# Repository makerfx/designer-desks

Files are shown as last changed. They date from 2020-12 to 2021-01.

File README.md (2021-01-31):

# Designer Desks

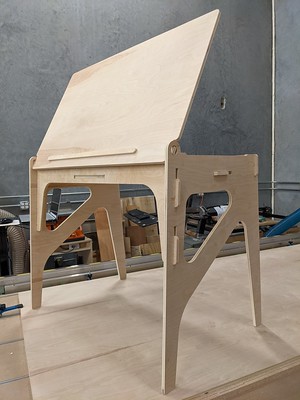
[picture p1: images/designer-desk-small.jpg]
Photo of Designer Desk with top open


The Maker Effect Foundation makes art desks for underprivileged youth in Central Florida. We cut them at MakerFX Makerspace on a Forest CNC MakerFab 5x10 CNC Router with a 5hp spindle, then volunteers sand and prep them for delivery. Each desk is stocked with art supplies. In addition, we have local artists who decorate some of the desks before delivery. 

We hope you will take these designs and make art desks for kids in your area! If you'd like to contact us to learn more, please email us at [info@makerfx.org](mailto:info@makerfx.org)

Design files are stored on GitHub by version. Make sure to use the download button to get the binary version of the file you need.
We have an illustrator outline of the desk top for those creating desk art. [(Download link)](https://github.com/makerfx/designer-desks/raw/main/Art-Desktop-outline.ai)

[Project Photos on Flickr](https://flic.kr/s/aHsmSCwJ4k)

Thanks to [HuntonBrady Architects](http://huntonbrady.com) for the desk design

Thanks to Adam Temple for making awesome assembly instructions!

Thanks to [Forest CNC](http://forestscientific.com/) for helping us obtain an amazing CNC router to make the desks for the initial run in Dec 2020

Thanks to Home Depot for discounting the [1/2 birch plywood](https://www.homedepot.com/p/Columbia-Forest-Products-1-2-in-x-4-ft-x-8-ft-PureBond-Birch-Plywood-833185/100020218) used for the project

Thanks to Boys & Girls Clubs of Central Florida for acting as a distribution partner for the desks

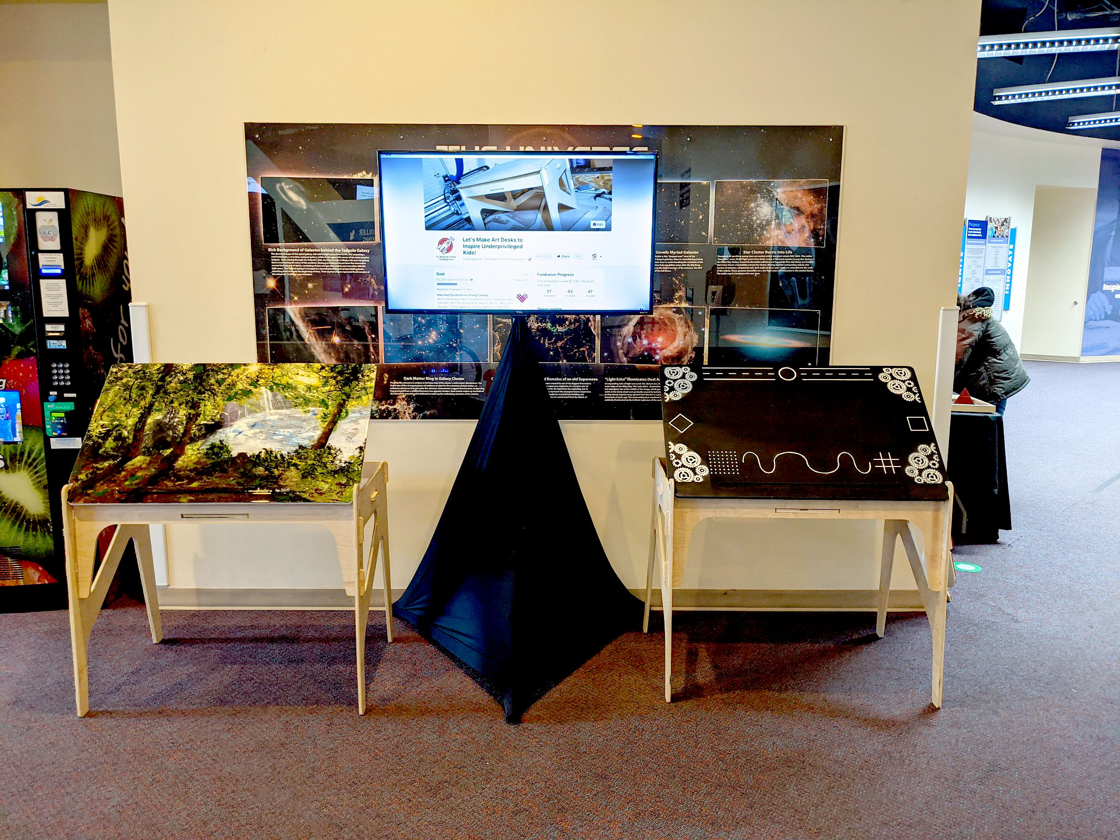
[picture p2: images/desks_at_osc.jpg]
Desks at OSC


This project is funded in part by Orange County Government through the Arts & Cultural Affairs Program.

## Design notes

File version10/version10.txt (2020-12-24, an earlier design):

Merged Layers
Reduced size of tab on lower desk section by 1/32 to help attachment.

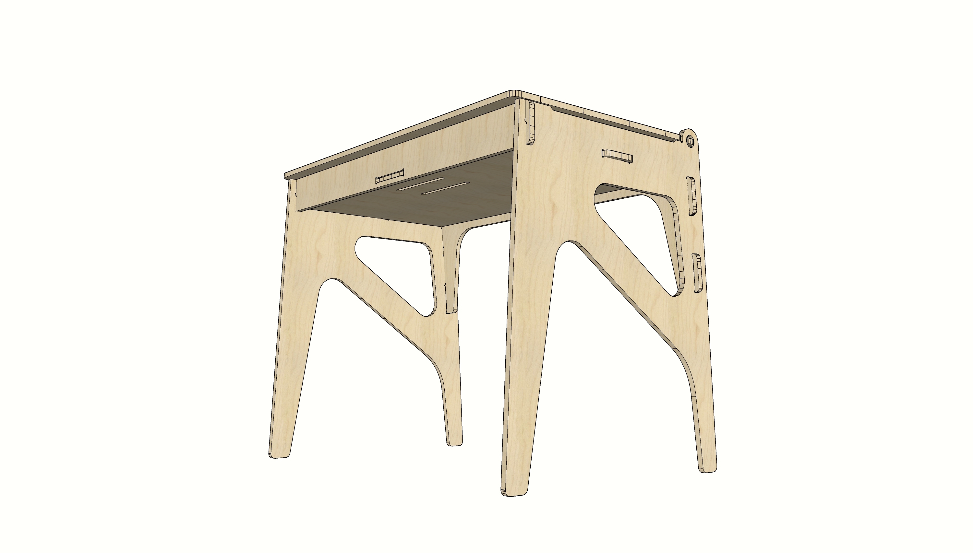
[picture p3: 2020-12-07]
renders/View5.jpg

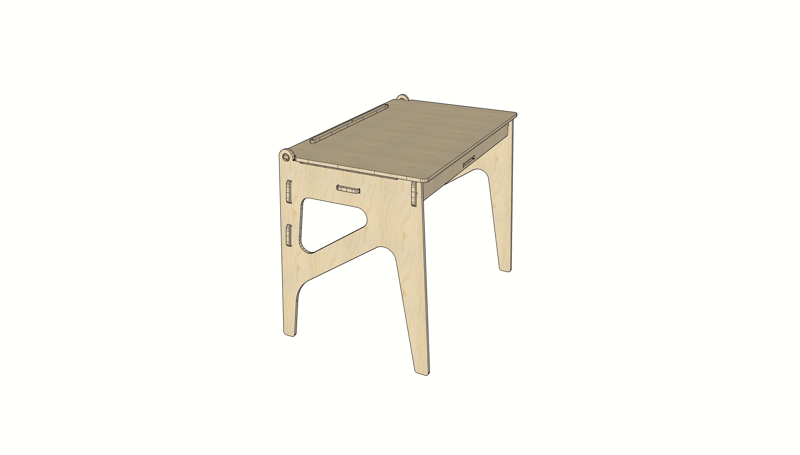
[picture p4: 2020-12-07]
renders/View6.jpg

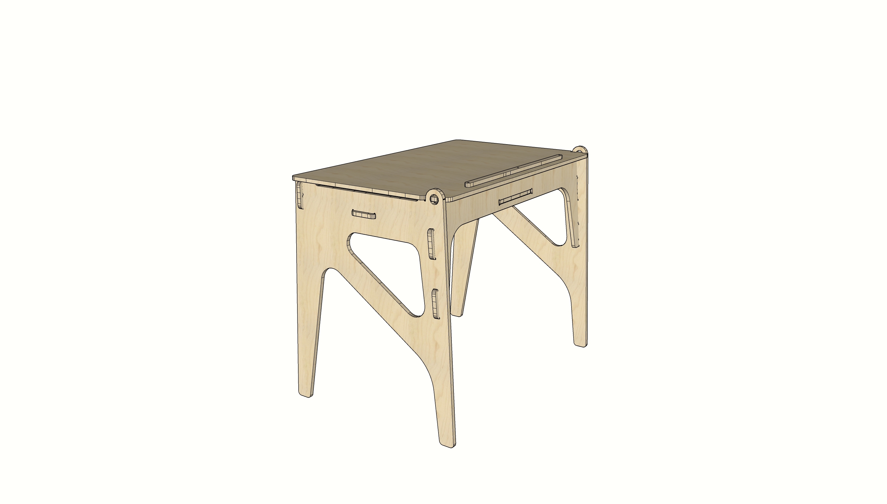
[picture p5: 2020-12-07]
renders/View4.jpg

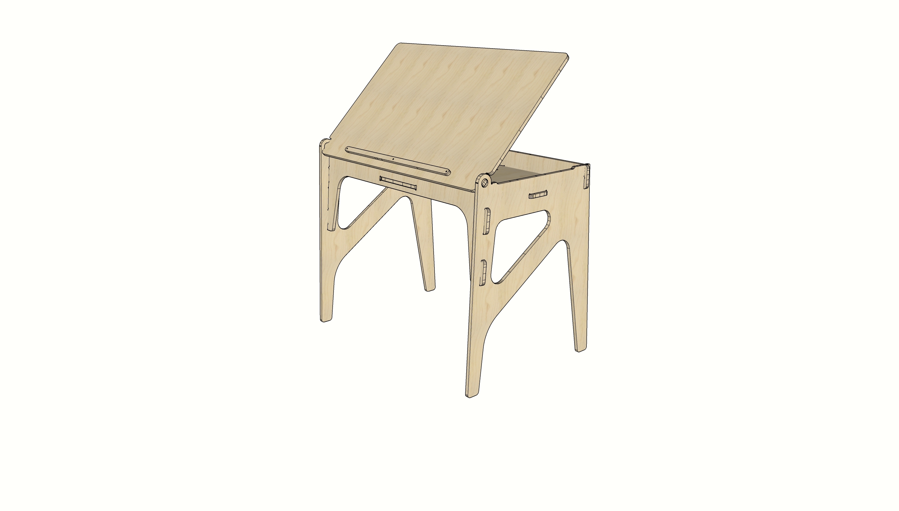
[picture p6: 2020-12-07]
renders/View1.jpg

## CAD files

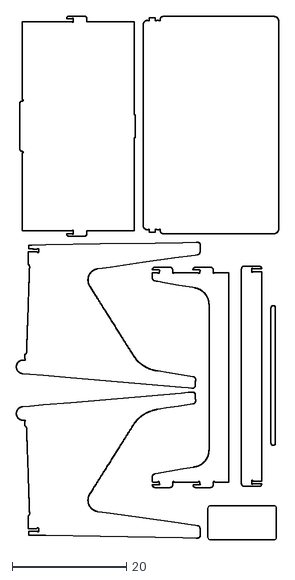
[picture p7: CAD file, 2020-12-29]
version11/Maker Desk V11 - 2 Pass.dxf
45.9 x 91.7

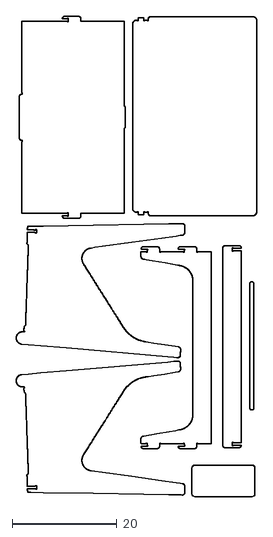
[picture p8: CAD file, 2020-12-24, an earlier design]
version10/Maker Desk V10 - 2 Pass.dxf
45.9 x 91.7

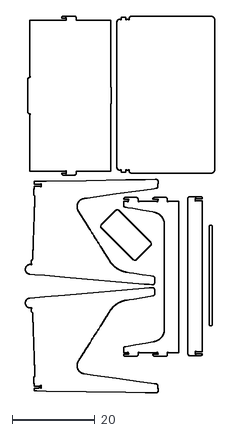
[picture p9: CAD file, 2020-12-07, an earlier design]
version8/Maker Desk V8 - 2 Pass.dxf
45.9 x 91.3

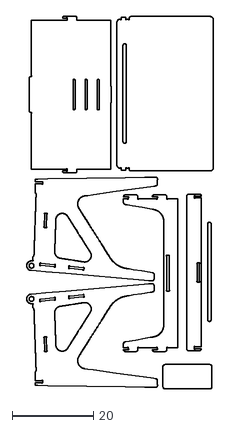
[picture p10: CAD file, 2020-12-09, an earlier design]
version9/Maker Desk V9 - 2 Pass.dxf
45.9 x 91.7

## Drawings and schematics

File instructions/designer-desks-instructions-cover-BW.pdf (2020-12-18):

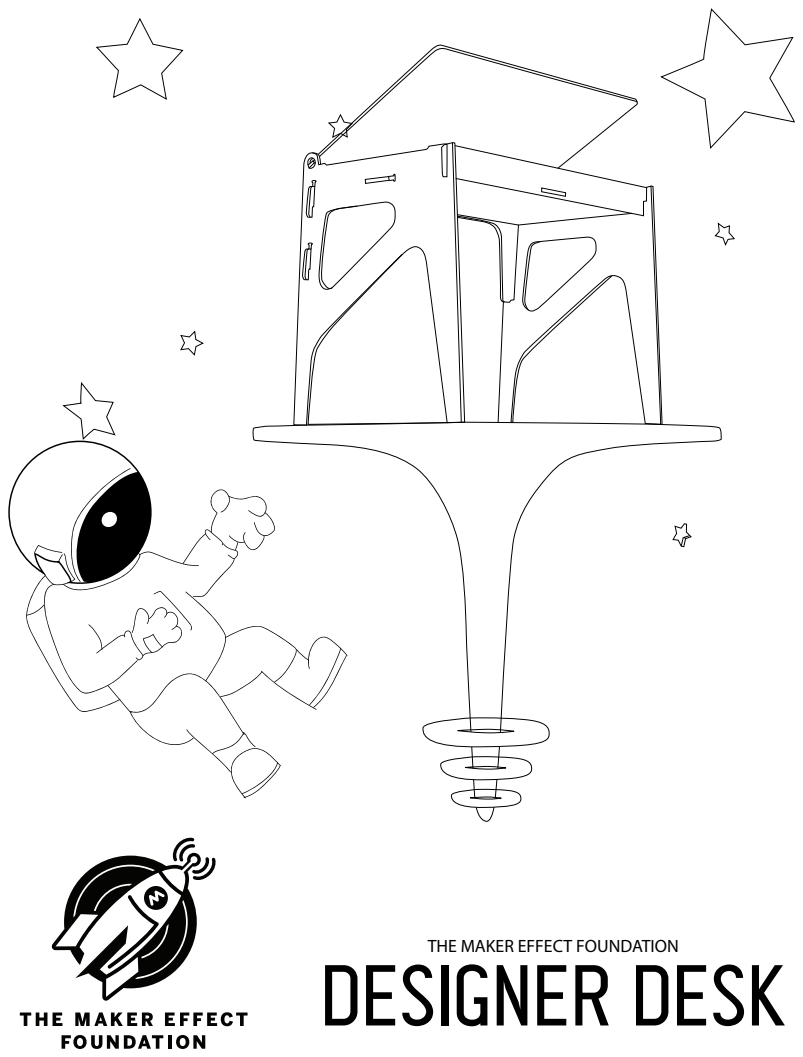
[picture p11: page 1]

THE MAKER EFFECT FOUNDATION
Designer Desk

# Designer Desk

# WHAT YOU NEED

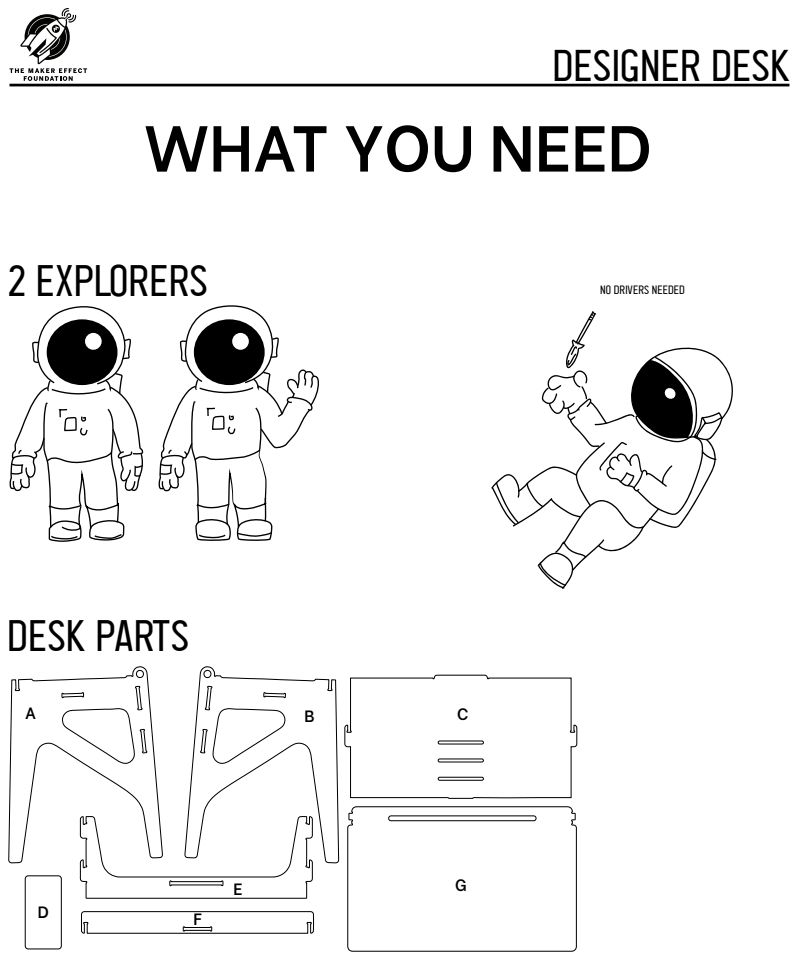
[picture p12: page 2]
2 explorers; no drivers needed; DESK PARTS

A
B

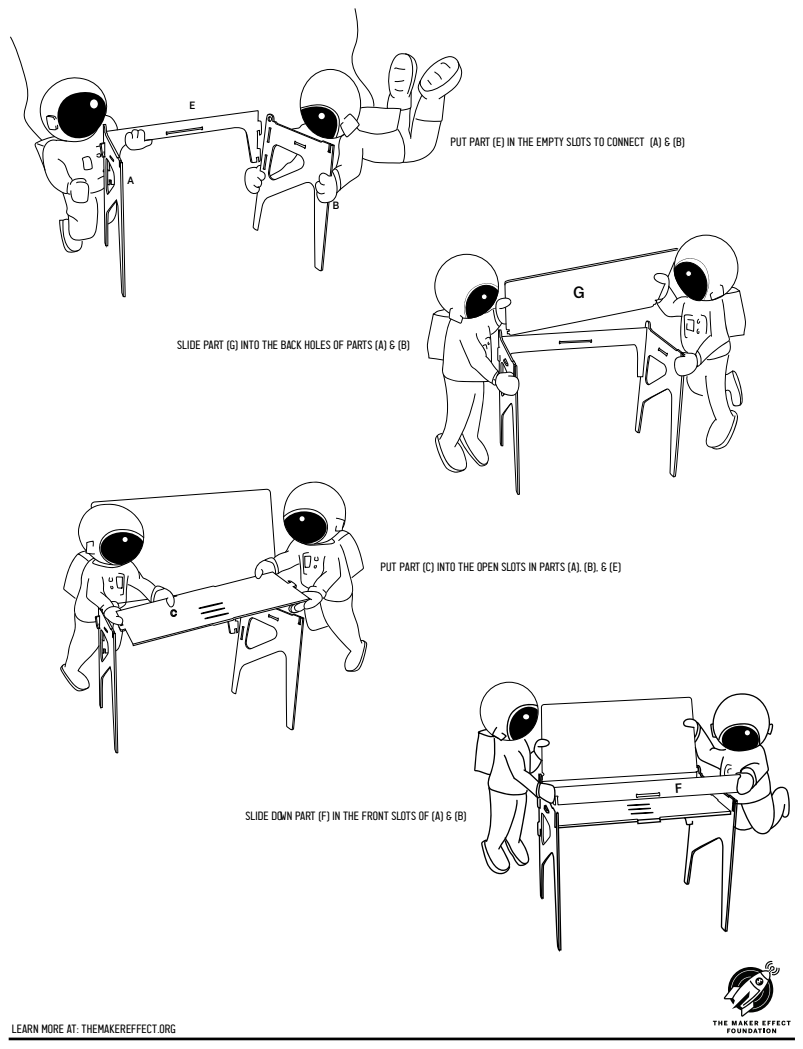
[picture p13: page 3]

Put part (E) in the empty slots to connect (A) & (B)

Slide part (G) into the back holes of parts (A) & (B)

Put part (C) into the open slots in parts (A), (B), & (E)

Slide down part (F) in the front slots of (A) & (B)

LEarn more at: themakereffect.org

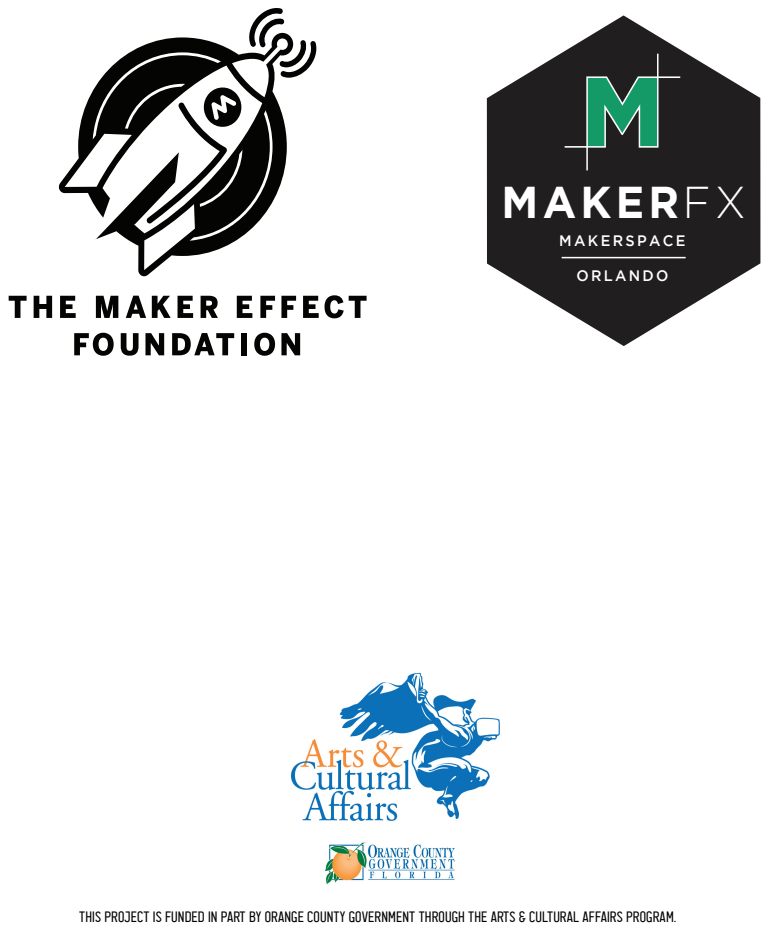
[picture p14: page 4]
MAKERFX; MAKERSPACE; ORLANDO

This project is funded in part by Orange County Government through the Arts & Cultural Affairs Program.

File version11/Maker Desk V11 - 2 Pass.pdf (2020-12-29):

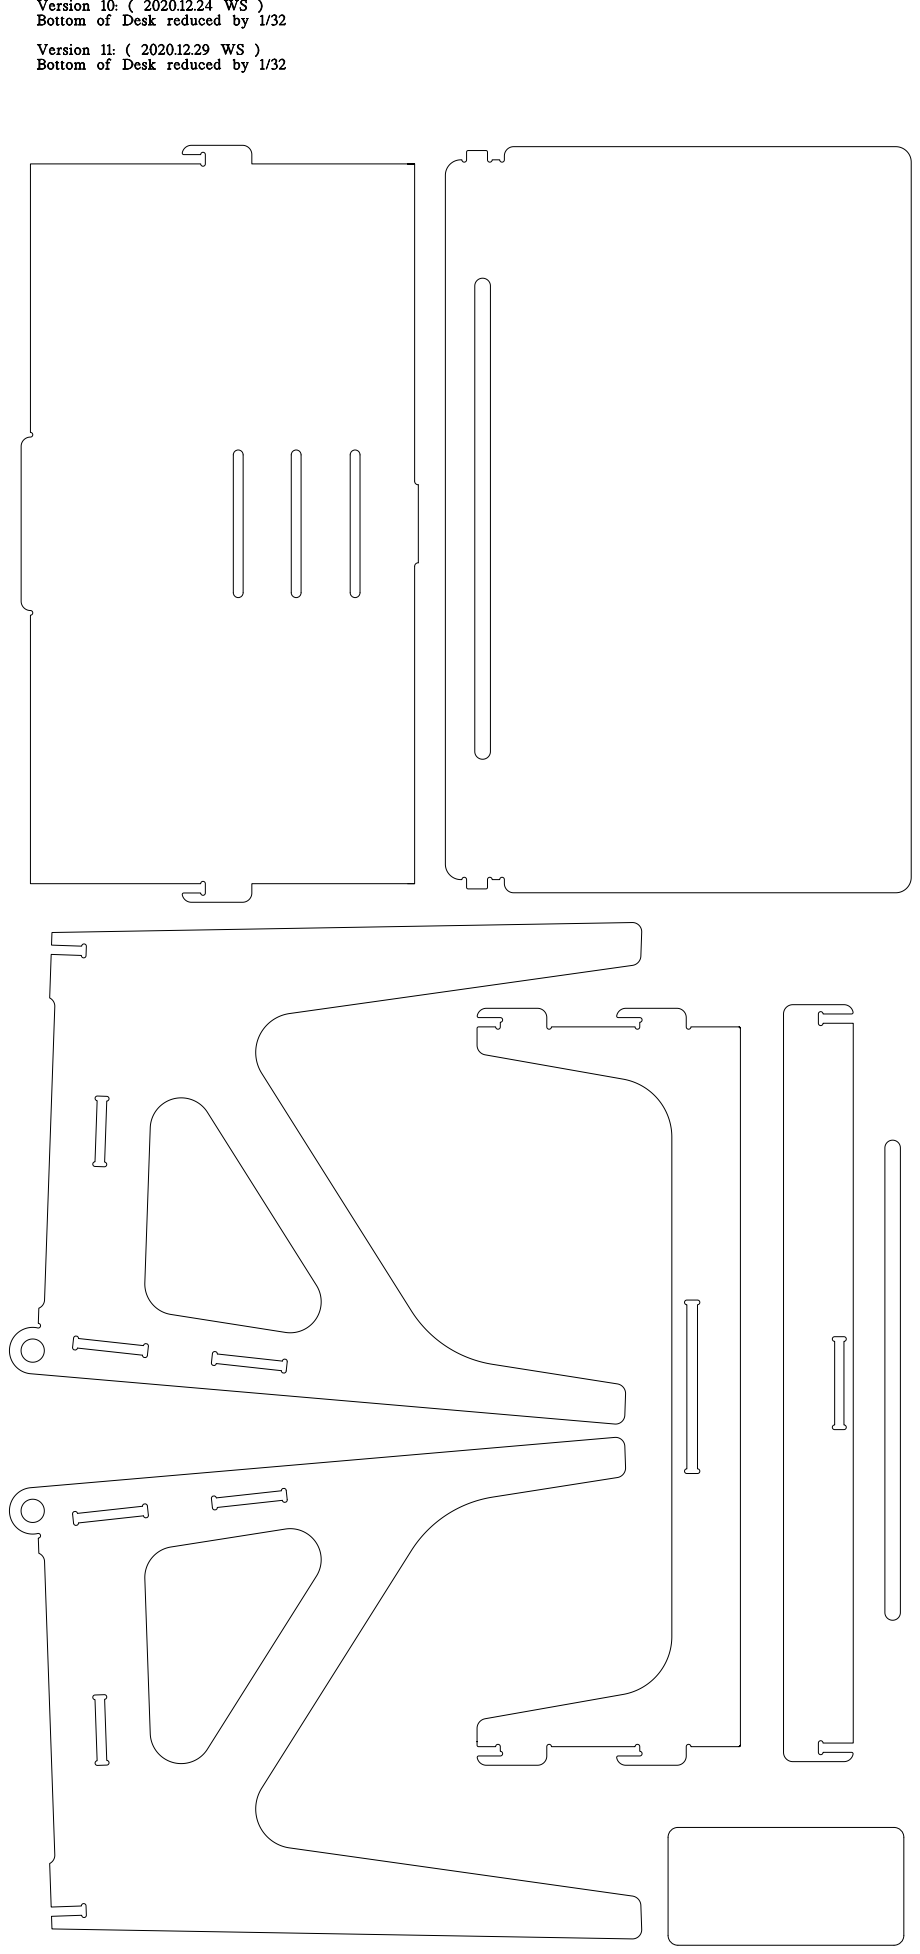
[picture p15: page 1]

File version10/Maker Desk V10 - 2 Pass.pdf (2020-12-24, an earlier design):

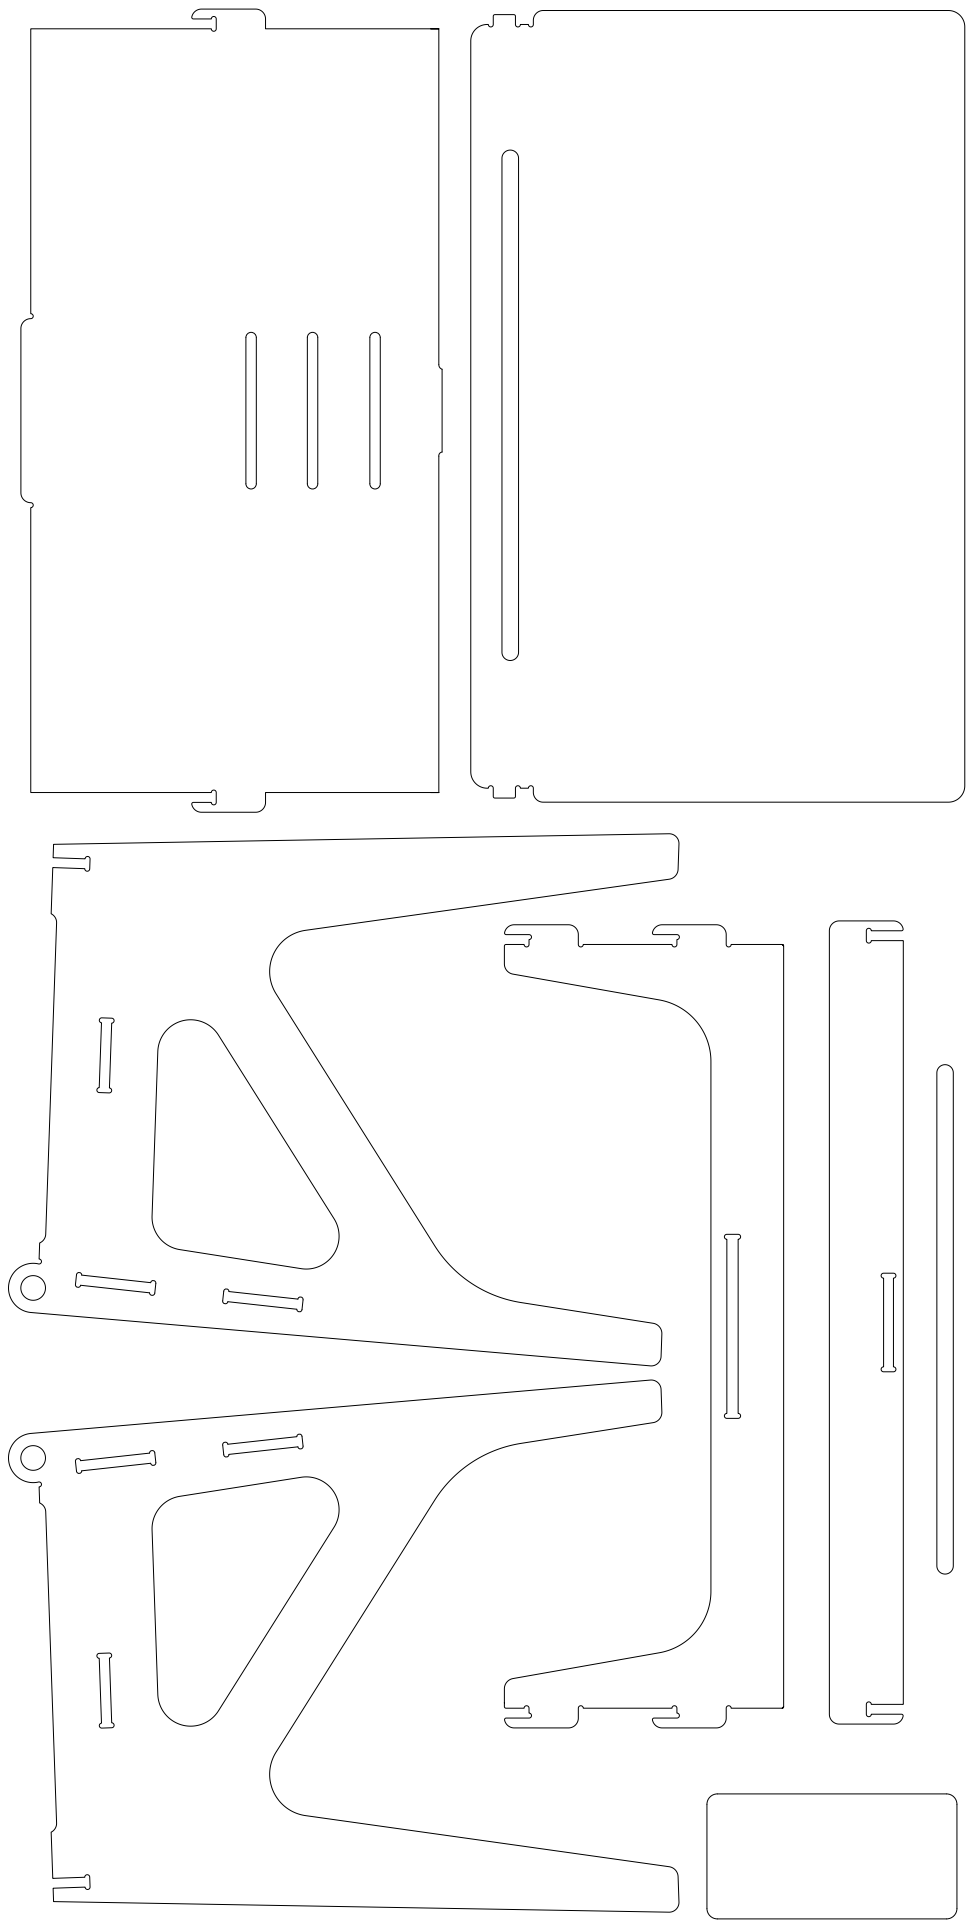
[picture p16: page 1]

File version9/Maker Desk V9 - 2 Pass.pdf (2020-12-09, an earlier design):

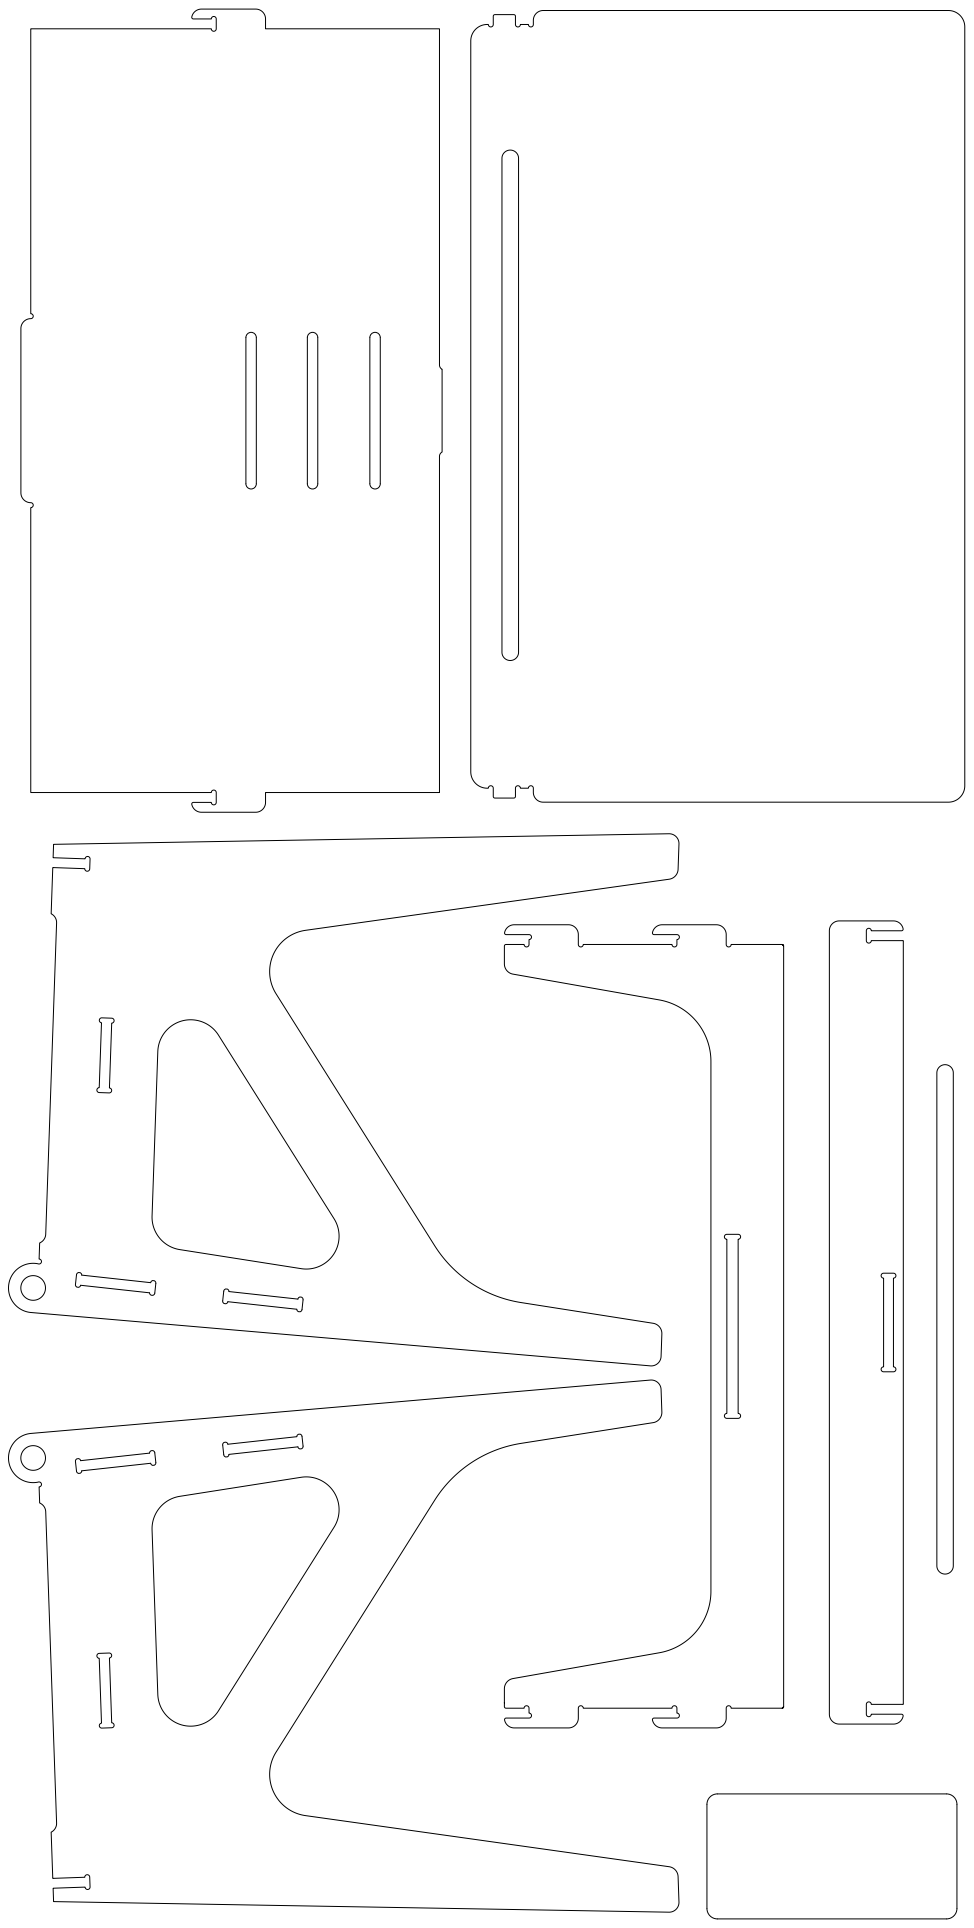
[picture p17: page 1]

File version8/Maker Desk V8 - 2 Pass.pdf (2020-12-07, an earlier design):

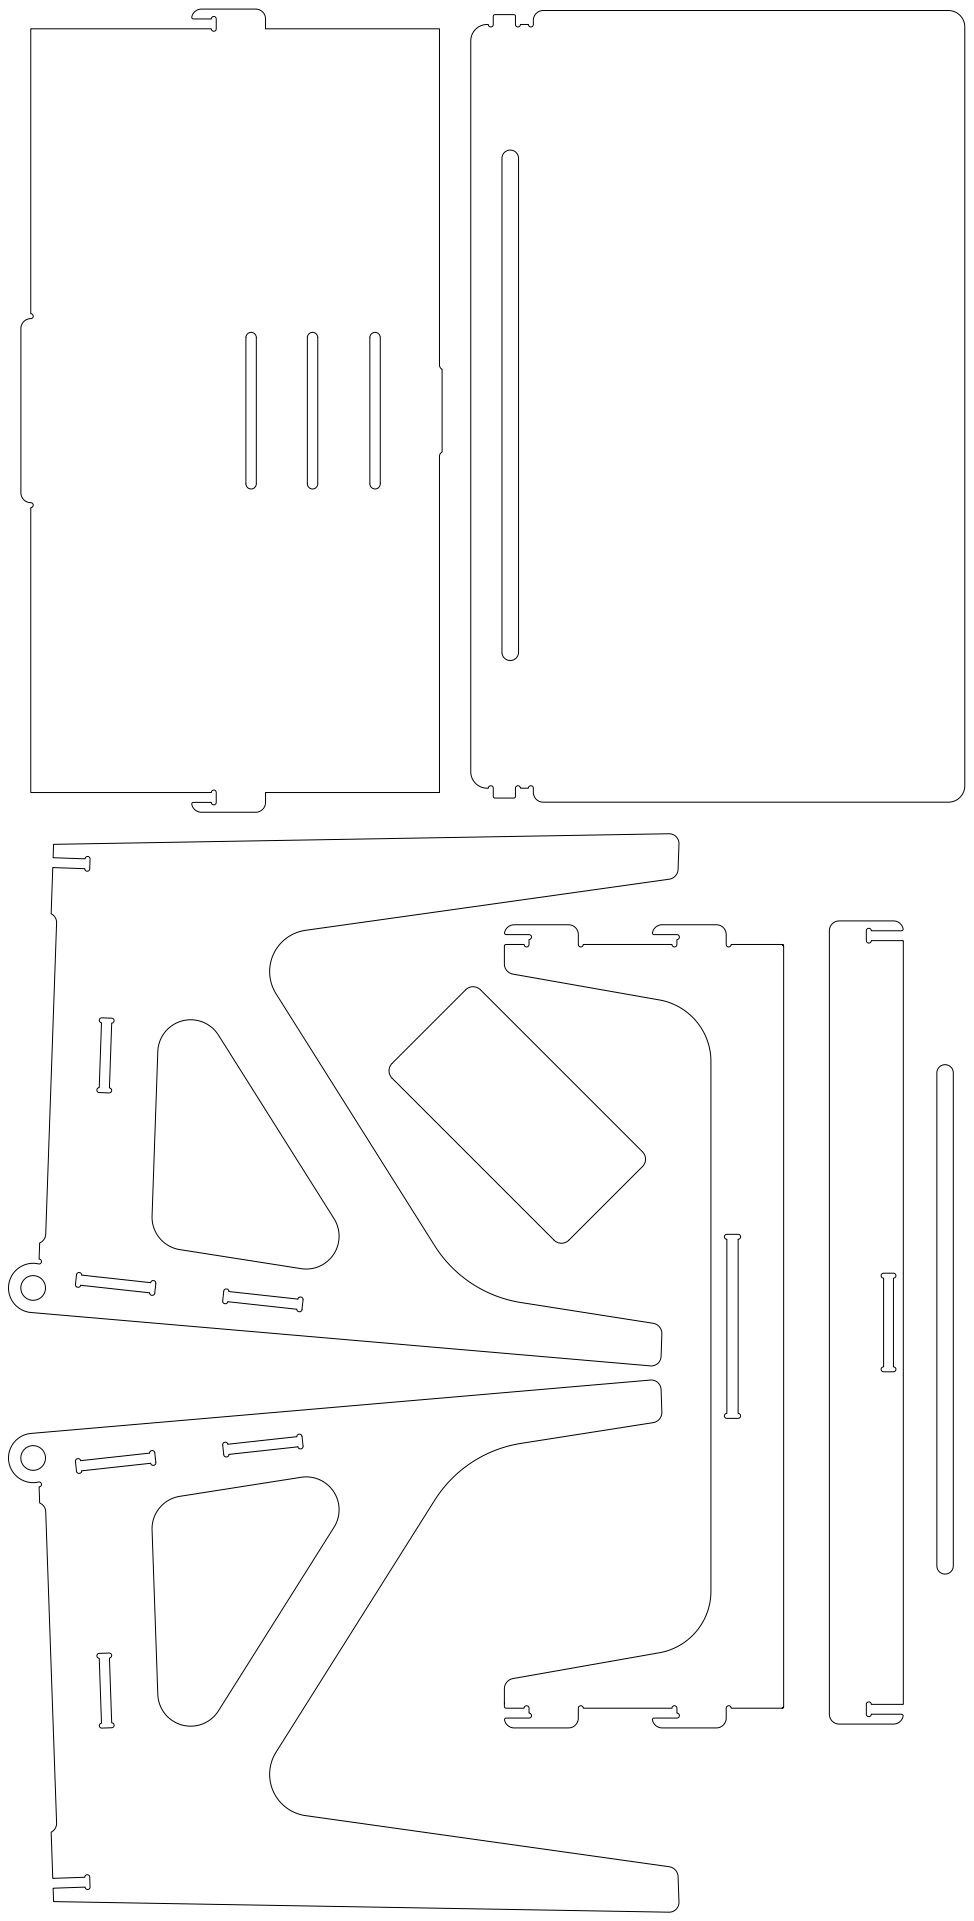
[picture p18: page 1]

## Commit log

2020-12-07 Upload V8
    Version 8 of the desk is the first usable version, and includes higher Z movement for travel to avoid surface contact.
    [Maker Desk V8 - 2 Pass.dxf]
2020-12-07 move files into version folder
    [Maker Desk V8 - 2 Pass.dxf]
2020-12-08 Add files via upload
    Move Top Prop Back to Corner to address moving during cut.
    [Maker Desk V9 - 2 Pass.dxf]
2020-12-09 move v9 into folder
    [Maker Desk V9 - 2 Pass.dxf]
2020-12-23 Credit Adam Temple for assembly instructions
2020-12-24 Add files via upload
    Reduced number of layers and reduced tab size on lower section of desk by 1/32 where the lower desk attaches and locks into front
    [Maker Desk V10 - 2 Pass.dxf]
2020-12-24 Add files via upload
    Revised Version 10
    Merged Layers
    Reduced Desk Bottom by 1/32 however, left tab at same distance from center,
    [Maker Desk V10 - 2 Pass.dxf]
2020-12-29 Reduced Lower Part of Desk by another 1/32
    Reduced the lower desk size by 1/32, but leaving tab sizes.
    [Maker Desk V11 - 2 Pass.dxf]
